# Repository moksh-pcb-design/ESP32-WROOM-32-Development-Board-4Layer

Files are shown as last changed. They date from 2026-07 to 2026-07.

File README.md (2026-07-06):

# ESP32-WROOM-32 4-Layer Development Board

> A custom **4-layer ESP32-WROOM-32 Development Board** designed using **Altium Designer 25.1**, featuring USB Type-C connectivity, CH340C USB-to-UART interface, custom schematic symbols, custom PCB footprints, dedicated power and ground planes, and manufacturing-ready outputs.

---

# Project Overview

This project presents the design and development of a custom **4-layer ESP32-WROOM-32 Development Board** intended for embedded system development, firmware programming, debugging, IoT prototyping, and hardware validation.

Unlike using pre-built libraries, all major components were implemented using **custom-created schematic symbols and PCB footprints** developed directly from manufacturer datasheets. The complete PCB design workflow was performed in **Altium Designer 25.1**, including schematic capture, PCB layout, stack-up planning, component placement, routing, ERC/DRC verification, and manufacturing file generation.

This project demonstrates practical PCB design skills used in professional hardware development.

---

# Project Specifications

| Parameter | Value |
|---|---|
| PCB Software | Altium Designer 25.1 |
| PCB Layers | 4 Layers |
| MCU | ESP32-WROOM-32 |
| USB Interface | USB Type-C |
| USB-UART Interface | CH340C |
| Voltage Regulator | AMS1117-3.3V |
| Programming | Auto Reset & Auto Boot Circuit |
| Design Verification | ERC Passed, DRC Passed |
| Manufacturing Output | Gerber, NC Drill, BOM |

---

# Hardware Architecture

```text
USB Type-C (5V Input)
          │
          ▼
 AMS1117-3.3V Regulator
          │
          ▼
      ESP32-WROOM-32
          │
          ▼
CH340C USB-UART Interface
          │
          ▼
EN / BOOT Control Circuit
          │
          ▼
GPIO Headers & Expansion
```

---

# Design Workflow

```text
Datasheet Analysis
        │
        ▼
Custom Schematic Symbol Creation
        │
        ▼
Custom PCB Footprint Creation
        │
        ▼
Schematic Design
        │
        ▼
Component Placement
        │
        ▼
4-Layer Stack-up Planning
        │
        ▼
Power Distribution
        │
        ▼
Signal Routing
        │
        ▼
Ground Plane Implementation
        │
        ▼
ERC Verification
        │
        ▼
DRC Verification
        │
        ▼
Gerber & BOM Generation
```

---

# Key Features

- ESP32-WROOM-32 Module Integration
- Custom Schematic Symbols
- Custom PCB Footprints
- USB Type-C Power & Programming
- CH340C USB-to-UART Interface
- AMS1117-3.3V Power Supply
- Auto Reset Circuit
- Auto Boot Programming Circuit
- EN Reset Push Button
- BOOT Push Button
- GPIO Breakout Headers
- Power Status LED
- Dedicated Ground Plane
- Dedicated Power Plane
- Manufacturing Ready PCB
- ERC Verified
- DRC Verified
- Gerber Generated
- BOM Generated

---

# PCB Stack-up

| Layer | Description |
|---|---|
| Top Layer | Components & Signal Routing |
| Inner Layer 1 | Solid Ground Plane |
| Inner Layer 2 | Power Plane |
| Bottom Layer | Signal Routing |

The dedicated internal power and ground planes improve current distribution, reduce return path impedance, enhance signal integrity, and provide a cleaner PCB layout.

---

# PCB Layout

## Top Layer

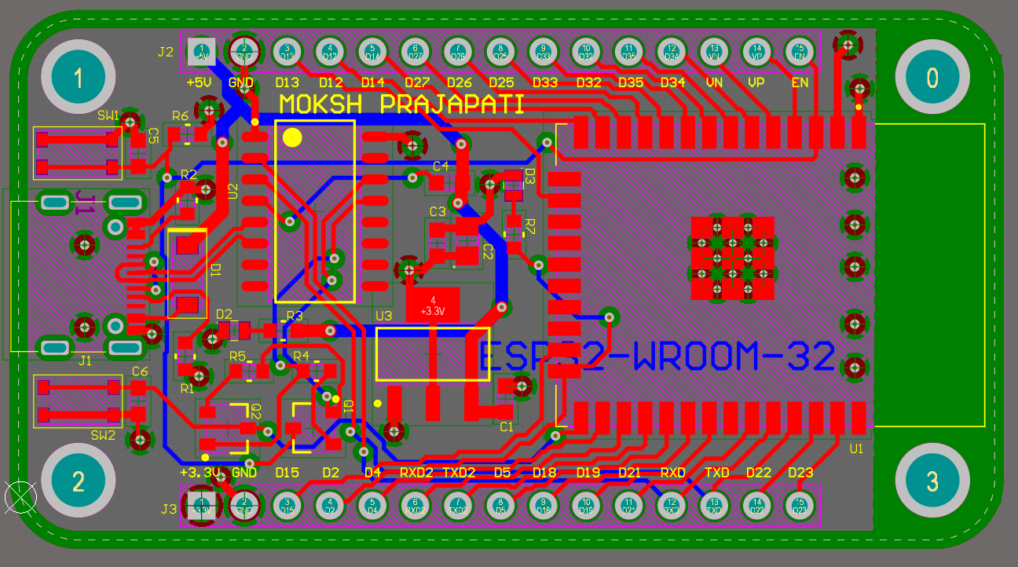
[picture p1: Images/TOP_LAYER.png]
Top Layer


---

## Bottom Layer

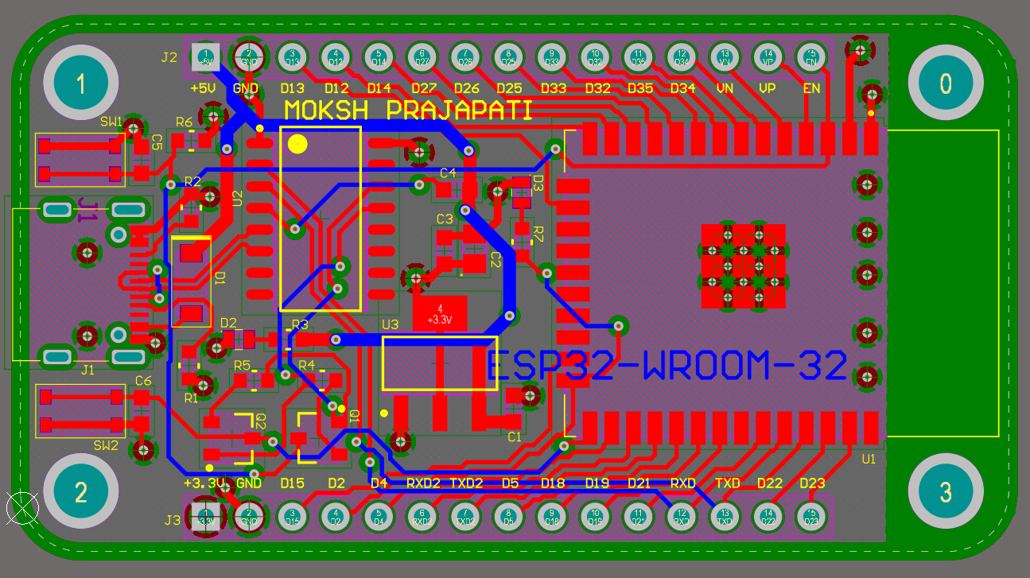
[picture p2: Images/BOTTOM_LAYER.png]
Bottom Layer


---

## Ground Plane

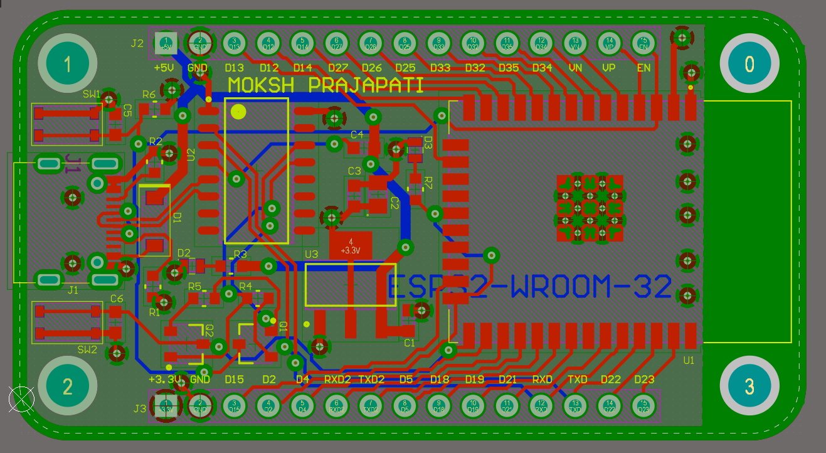
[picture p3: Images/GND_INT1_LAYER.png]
Ground Plane


---

## Power Plane

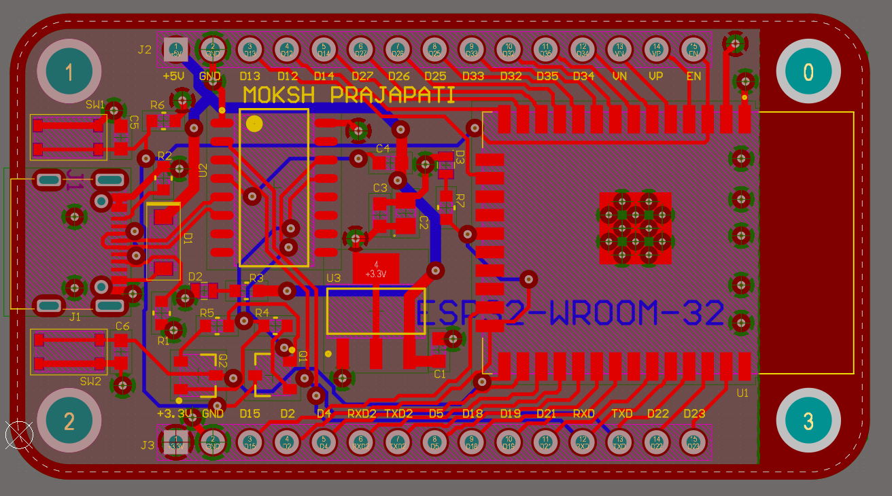
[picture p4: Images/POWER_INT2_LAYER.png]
Power Plane


---

# 3D Visualization

## Top View

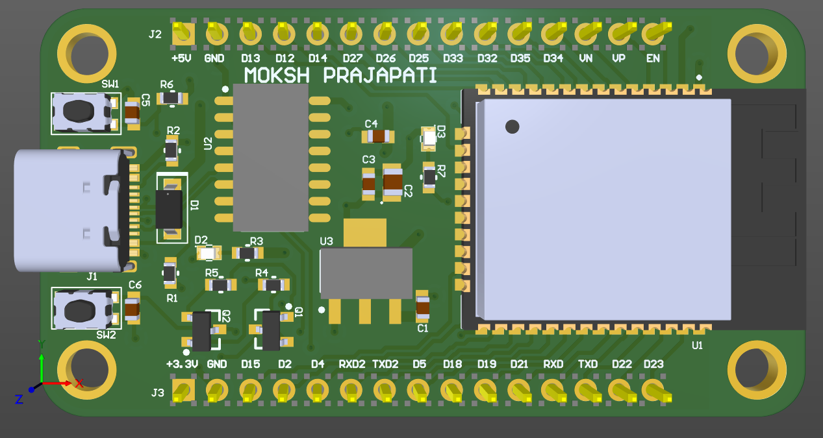
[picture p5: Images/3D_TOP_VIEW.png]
Top


---

## Bottom View

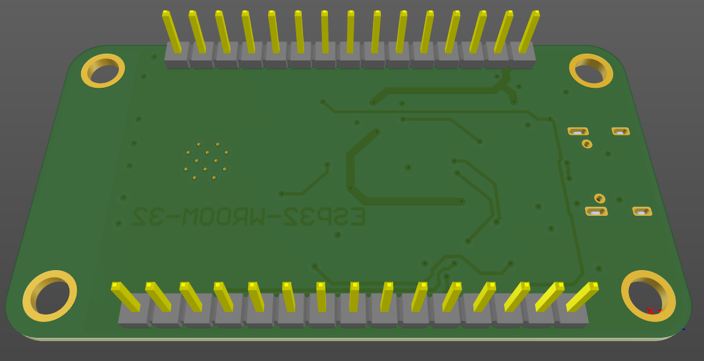
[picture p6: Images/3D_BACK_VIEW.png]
Bottom


---

# Schematic

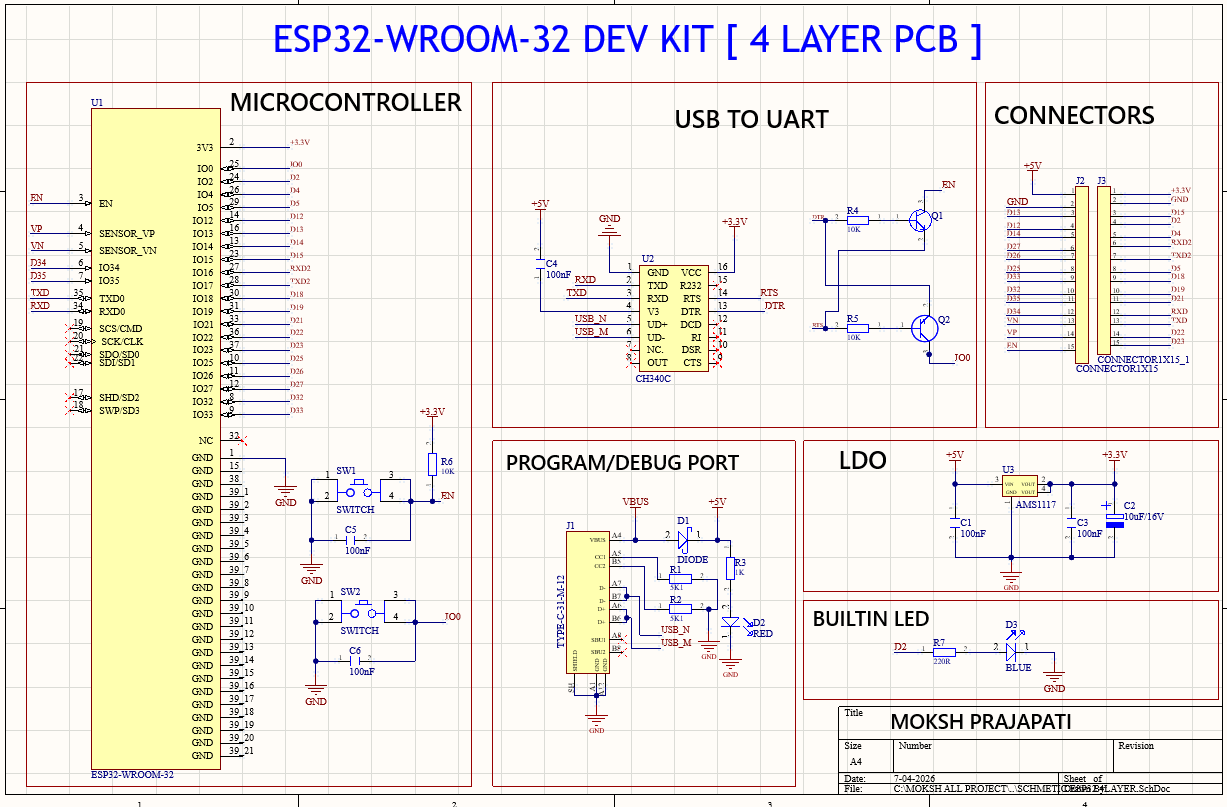
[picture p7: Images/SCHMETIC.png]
Schematic


---

# Major Components

- ESP32-WROOM-32
- CH340C USB-to-UART Converter
- AMS1117-3.3V Voltage Regulator
- USB Type-C Connector
- Push Buttons
- LEDs
- Crystal Oscillator
- Capacitors
- Resistors
- GPIO Headers

---

# Design Highlights

### Custom Library Development

Instead of using pre-built libraries, all schematic symbols and PCB footprints were created manually using manufacturer datasheets. Footprints were verified for pad dimensions, pin spacing, package outline, and mechanical accuracy before PCB implementation.

---

### PCB Layout Planning

- Functional component grouping
- Optimized component placement
- Short power traces
- Dedicated power distribution
- Clean signal routing
- Ground return optimization
- Proper via usage
- Layer-wise routing strategy

---

### Design Verification

Electrical and physical verification was performed before manufacturing file generation.

- ERC Completed
- DRC Completed
- PCB Rule Verification
- Manufacturing Output Verification

---

# Manufacturing Outputs

The repository contains complete manufacturing files including:

- Altium Project Files
- PCB Layout Files
- Schematic Files
- PCB Libraries
- Schematic Libraries
- Gerber Package
- NC Drill Files
- Bill of Materials (BOM)
- ERC Report
- DRC Report

---

# Skills Demonstrated

### PCB Design

- Multi-layer PCB Design
- Schematic Capture
- PCB Layout Design
- Component Placement
- Signal Routing
- Power Distribution
- Ground Plane Design
- Stack-up Planning
- Design Rule Verification

### Library Development

- Custom Schematic Symbol Creation
- Custom PCB Footprint Creation
- Datasheet Interpretation
- Library Management

### Hardware Design

- ESP32 Hardware Integration
- USB Interface Design
- Power Supply Design
- Embedded Hardware Design
- Auto Programming Circuit

### Manufacturing Preparation

- Gerber Generation
- BOM Generation
- Production Output Preparation
- Design Documentation

---

# Repository Structure

```
Design_Files/
Images/
Libraries/
Manufacturing_Files/
Reports/
README.md
```

---

# Future Improvements

- PCB Fabrication & Assembly
- Functional Hardware Testing
- USB ESD Protection Enhancement
- High-Speed USB Routing Optimization
- Impedance Controlled Differential Pair Routing
- EMI/EMC Performance Optimization

---

# Author

## Moksh Prajapati

Electronics Engineering Student

**Interested in**

- PCB Design
- Hardware Design
- Embedded Systems
- High-Speed PCB Design
- IoT Hardware Development

---

⭐ If you found this project useful, consider giving it a Star.

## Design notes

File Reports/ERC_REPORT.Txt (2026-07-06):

Class	Document	Source	Message	Time	Date	No.

[Warning]	SCHMETIC ESP32 4LAYER.SchDoc	Compiler	Net D34 has no driving source (Pin J2-12, Pin U1-6)	15:08:20	01-07-2026	1
[Warning]	SCHMETIC ESP32 4LAYER.SchDoc	Compiler	Net D35 has no driving source (Pin J2-11, Pin U1-7)	15:08:20	01-07-2026	2
[Warning]	SCHMETIC ESP32 4LAYER.SchDoc	Compiler	Net EN has no driving source (Pin C5-2, Pin J2-15, Pin Q1-3, Pin R6-1, Pin SW1-3, Pin SW1-4, Pin U1-3)	15:08:20	01-07-2026	3
[Warning]	SCHMETIC ESP32 4LAYER.SchDoc	Compiler	Net VN has no driving source (Pin J2-13, Pin U1-5)	15:08:20	01-07-2026	4
[Warning]	SCHMETIC ESP32 4LAYER.SchDoc	Compiler	Net VP has no driving source (Pin J2-14, Pin U1-4)	15:08:20	01-07-2026	5
[Info]	ESP32 WROOM32 4LAYER.PrjPcb	Compiler	Compile successful, no errors found.	15:08:20	01-07-2026	6

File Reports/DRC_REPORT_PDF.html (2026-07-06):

Altium

# Design Rule Verification Report

Date: | | 30-06-2026
Time: | | 14:44:07
Elapsed Time: | | 00:00:00
Filename: | | C:\MOKSH ALL PROJECT\ALTIUM PROJECTS\ESP32 WROOM32 ALTIUMM [ 4 LAYER ]\ESP32 WROOM32 4LAYER\PCB ESP32 WROOM 4 LAYER.PcbDoc

Warnings: | | 0
Rule Violations: | | 0

## Summary

Warnings | Count
Total | 0

Rule Violations | Count
Clearance Constraint (Gap=0mm) (All),(All) | 0
Short-Circuit Constraint (Allowed=No) (All),(All) | 0
Un-Routed Net Constraint ( (All) ) | 0
Modified Polygon (Allow modified: No), (Allow shelved: No) | 0
Width Constraint (Min=0.3mm) (Max=0.8mm) (Preferred=0.5mm) (All) | 0
Routing Topology Rule(Topology=Shortest) (All) | 0
Power Plane Connect Rule(Relief Connect )(Expansion=0.508mm) (Conductor Width=0.254mm) (Air Gap=0.254mm) (Entries=4) (All) | 0
Hole Size Constraint (Min=0.025mm) (Max=4mm) (All) | 0
Hole To Hole Clearance (Gap=0mm) (All),(All) | 0
Minimum Solder Mask Sliver (Gap=0mm) (All),(All) | 0
Silk To Solder Mask (Clearance=0mm) (IsPad),(All) | 0
Silk to Silk (Clearance=0mm) (All),(All) | 0
Net Antennae (Tolerance=0mm) (All) | 0
Height Constraint (Min=0mm) (Max=25.4mm) (Prefered=12.7mm) (All) | 0
Total | 0

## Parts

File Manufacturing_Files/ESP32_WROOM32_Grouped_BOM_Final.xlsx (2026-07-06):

Name | Description | Designator | Footprint | LibRef | Quantity | Manufacturer | MPN | Notes
100nF | UNPOLERIZED | C1,C3,C4,C5,C6 | CAPACITOR0603-100nF | CAPACITOR.. | 5 | Murata | GRM188R71C104KA01D
10uF/16V |  | C2 | CAPACITOR0805-10uF | TANTALUM CAPACITOR | 1 | Murata | GRM21BR61C106KE15L
DIODE |  | D1 | Schottky diode | DIODE | 1 | Micro Commercial Components | B5817W | Schottky
RED |  | D2 | LED0603-RED | LED | 1 | Lite-On | LTST-C190KRKT
BLUE |  | D3 | LED0603-BLUE | LED | 1 | Lite-On | LTST-C190TBKT
TYPE-C-31-M-12 | TYPE-C-31-M-12 | J1 | USB_TYPE_C | USB TYPE C | 1 | GCT | TYPE-C-31-M-12
CONNECTOR1X15 |  | J2 | 1X15 PIN HEADER | CONNECTOR1X15 | 1 | Harwin | HTSW-115-07-G-S
CONNECTOR1X15_1 |  | J3 | 1X15 PIN HEADER | CONNECTOR1X15_1 | 1 | Harwin | HTSW-115-07-G-S
MMBT3904LT1G |  | Q1,Q2 | NPN Transistor | NPN TRANSISTOR | 2 | onsemi | MMBT3904LT1G
5K1 |  | R1,R2 | RESISTOR0603-5K1 | RES0805 | 2 | Yageo | RC0603FR-075K1L
1K |  | R3 | RESISTOR0603-1k | RES0805 | 1 | Yageo | RC0603FR-071KL
10K |  | R4,R5,R6 | RESISTOR0603-10K | RES0805 | 3 | Yageo | RC0603FR-0710KL
220R |  | R7 | RESISTOR0603-220 | RES0805 | 1 | Yageo | RC0603FR-07220RL
SWITCH | SWITCH PUSH SPST-NO 0.1A 32V | SW1,SW2 | PUSHBUTTON | SWITCH | 2 | C&K | PTS645SL43SMTR92LFS
ESP32-WROOM-32 | Bluetooth, WiFi 802.11b/g/n, Bluetooth v4.2 +EDR, Class 1, 2 and 3 Transceiver Module 2.4GHz ~ 2.5GHz Antenna Not Included, U.FL Surface Mount | U1 | MODULE_ESP32-WROOM-32 | ESP32-WROOM-32 | 1 | Espressif Systems | ESP32-WROOM-32E | Main MCU
CH340C |  | U2 | CH340C | CH340C | 1 | WCH | CH340C | USB-UART
AMS1117 |  | U3 | AMS1117-3.3 | AMS1117 | 1 | Advanced Monolithic Systems | AMS1117-3.3 | 3.3V Regulator
